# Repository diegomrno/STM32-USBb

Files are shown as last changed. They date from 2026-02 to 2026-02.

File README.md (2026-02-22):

# STM32-USBb

STM32-USBb is an **experimental PCB** based on an **STM32 microcontroller**, designed for research and prototyping purposes.

This board is part of the **Raptor project** by [Infinite](https://github.com/infiniteHQ).

> [!IMPORTANT]
> This PCB is **not production-ready**.  
> It is purely experimental and intended only for early development and future work within the Infinite project.

## Preview

Preview

## PCB

PCB

## Components list (ref & role)

- **U1** : STM32 (STM32F103C8T6) microcontroller (main MCU)
- **U2** : 3.3 V linear voltage regulator

- **Y3** : 16 MHz external crystal (MCU clock)

- **J1, J2, J3** : Pin headers (GPIO / debug / expansion)
- **J4** : USB Micro-B connector (power + USB data)

- **SW1** : Power / mode selection switch

- **D1** : Status LED

- **FB1** : Ferrite bead (power supply noise filtering)

- **R3** : USB pull-up resistor
- **R2** : MCU reset / configuration pull resistor
- **R1, R4, R5** : Current limiting / configuration resistors

- **C1, C2** : Bulk input/output decoupling capacitors
- **C3, C4, C5, C6, C11** : MCU decoupling capacitors
- **C7** : Local bulk decoupling capacitor
- **C8, C9, C10** : Power rail filtering capacitors
- **C12, C13** : Crystal load capacitors

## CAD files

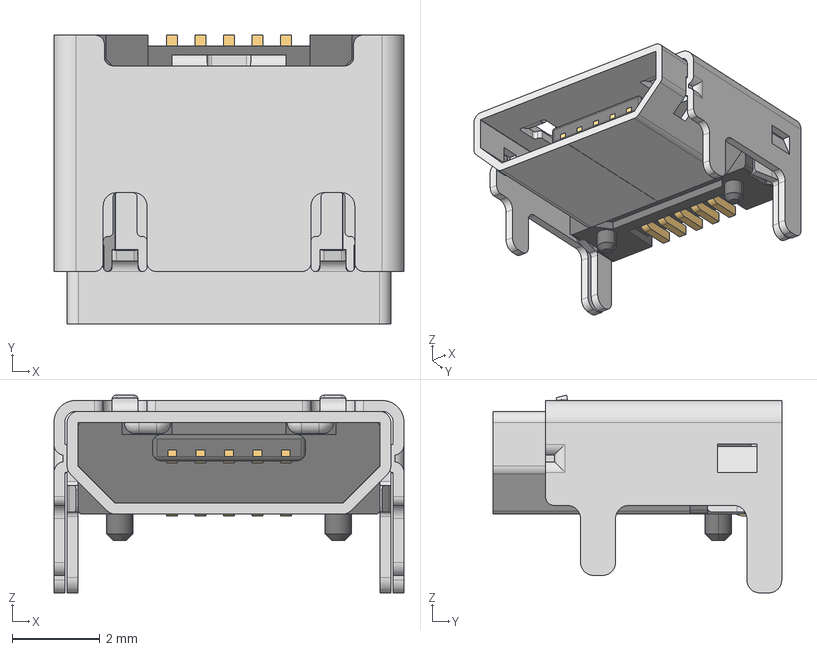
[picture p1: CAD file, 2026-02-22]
STM32-USBc/629105150521.stp
8.00 x 6.60 x 4.52 mm

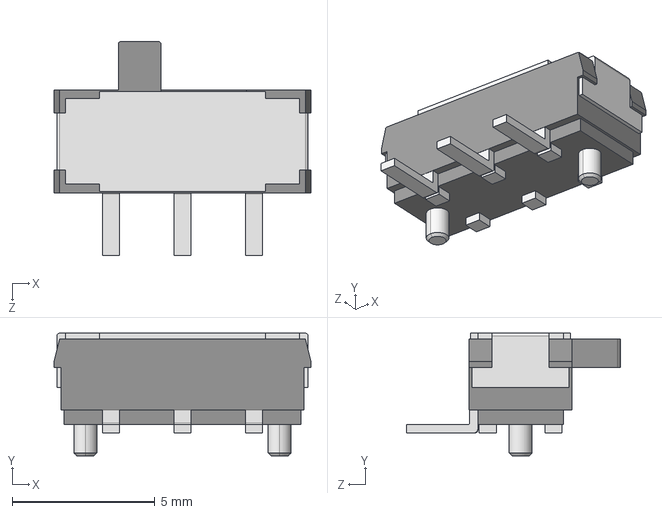
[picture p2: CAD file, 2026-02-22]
STM32-USBc/JS102011SAQN.STEP
9.00 x 4.30 x 7.50 mm

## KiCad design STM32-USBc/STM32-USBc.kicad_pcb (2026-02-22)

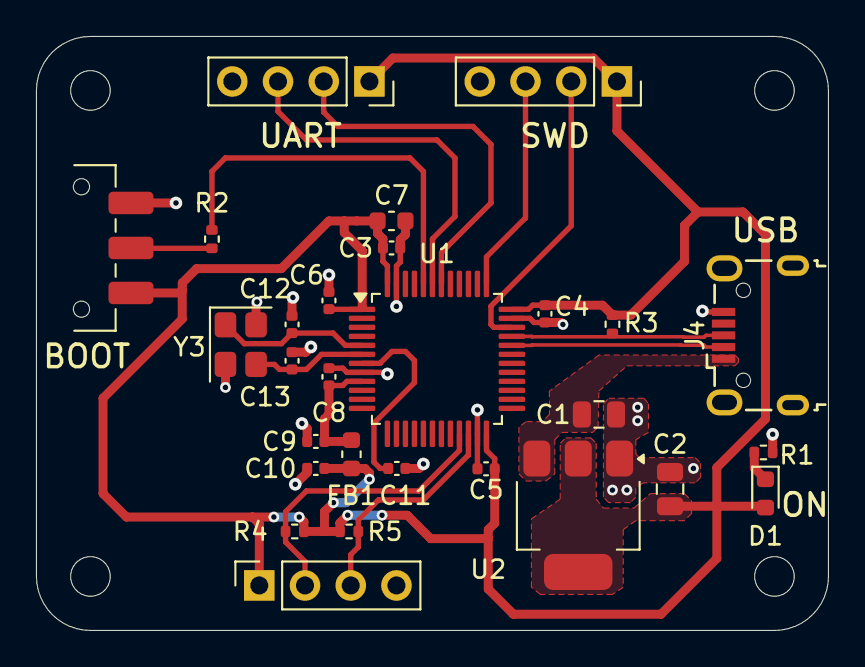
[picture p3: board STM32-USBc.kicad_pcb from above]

Board: 2 copper layers, 44.0 x 33.0 mm, 32 parts (0 on the bottom side), 18 nets.

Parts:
C1, C2: 22u; C_0805_2012Metric
C3, C4, C5, C6, C11: 100n; C_0402_1005Metric
C7: 10u; C_0603_1608Metric
C8: 10n; C_0402_1005Metric
C9, C10: 1u; C_0402_1005Metric
C12, C13: 10p; C_0402_1005Metric
D1: LED; LED_0603_1608Metric
FB1: FerriteBead; L_0603_1608Metric
H1, H2, H3, H4: MountingHole; MountingHole_2.2mm_M2
J1, J2, J3: Conn_01x04_Pin; PinSocket_1x04_P2.54mm_Vertical
J4: USB_B_Micro; USB_Micro-B_Wuerth_629105150521
R1, R3, R4, R5: 1k5; R_0402_1005Metric
R2: 10k; R_0402_1005Metric
SW1: SW_SPDT; SW_SPDT_CK_JS102011SAQN
U1: STM32F103C8T6; LQFP-48_7x7mm_P0.5mm
U2: AMS1117-3.3; SOT-223-3_TabPin2
Y3: 16MHz; Crystal_SMD_3225-4Pin_3.2x2.5mm

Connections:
+3.3V: C2.1, C3.1, C4.1, C5.1, C6.1, C7.1, C10.1, D1.2 (A), FB1.2, J1.1, J2.1, J3.1, R3.1, R4.1, R5.1, SW1.3 (C), U1.1 (VBAT), U1.24 (VDD), U1.36 (VDD), U1.48 (VDD), U2.2 (VO)
+3.3VA: C8.1, C9.1, FB1.1, U1.9 (VDDA)
/BOOT0: R2.2, U1.44 (BOOT0)
/HSE_IN: C12.1, U1.5 (PD0), Y3.1
/HSE_OUT: C13.1, U1.6 (PD1), Y3.3
/I2C2_SCL: J3.2, R4.2, U1.21 (PB10)
/I2C2_SDA: J3.3, R5.2, U1.22 (PB11)
/NRST: C11.1, U1.7 (NRST)
/PWR_LED_K: D1.1 (K), R1.1
/SWCLK: J1.3, U1.37 (PA14)
/SWDIO: J1.2, U1.34 (PA13)
/SW_BOOT0: R2.1, SW1.2 (B)
/USART1_RX: J2.3, U1.43 (PB7)
/USART1_TX: J2.2, U1.42 (PB6)
/USB_D+: J4.3 (D+), R3.2, U1.33 (PA12)
/USB_D-: J4.2 (D-), U1.32 (PA11)
GND: C1.2, C2.2, C3.2, C4.2, C5.2, C6.2, C7.2, C8.2, C9.2, C10.2, C11.2, C12.2, C13.2, J1.4, J2.4, J3.4, J4.5 (GND), R1.2, SW1.1 (A), U1.8 (VSSA), U1.23 (VSS), U1.35 (VSS), U1.47 (VSS), U2.1 (GND), Y3.2 (G), Y3.4 (G)
VBUS: C1.1, J4.1 (VBUS), U2.3 (VI)

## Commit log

2026-02-22 add 3d model for USB c receptacle
    [1054500101.stp, STM32-USBc.kicad_pcb, STM32-USBc.kicad_sch]
2026-02-22 pre rooting
    [STM32-USBc.kicad_pcb]
2026-02-22 3d model of switch + layout borders
    [JS102011SAQN.STEP, STM32-USBc.kicad_pcb, STM32-USBc.kicad_sch]
2026-02-22 switch to usb b
    [STM32-USBc.kicad_pcb, STM32-USBc.kicad_sch]
2026-02-22 final rooting and texts
    [1054500101.stp, 629105150521.stp, STM32-USBc.kicad_pcb]
